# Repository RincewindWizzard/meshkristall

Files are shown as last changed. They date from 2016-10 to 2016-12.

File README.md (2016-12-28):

# meshkristall
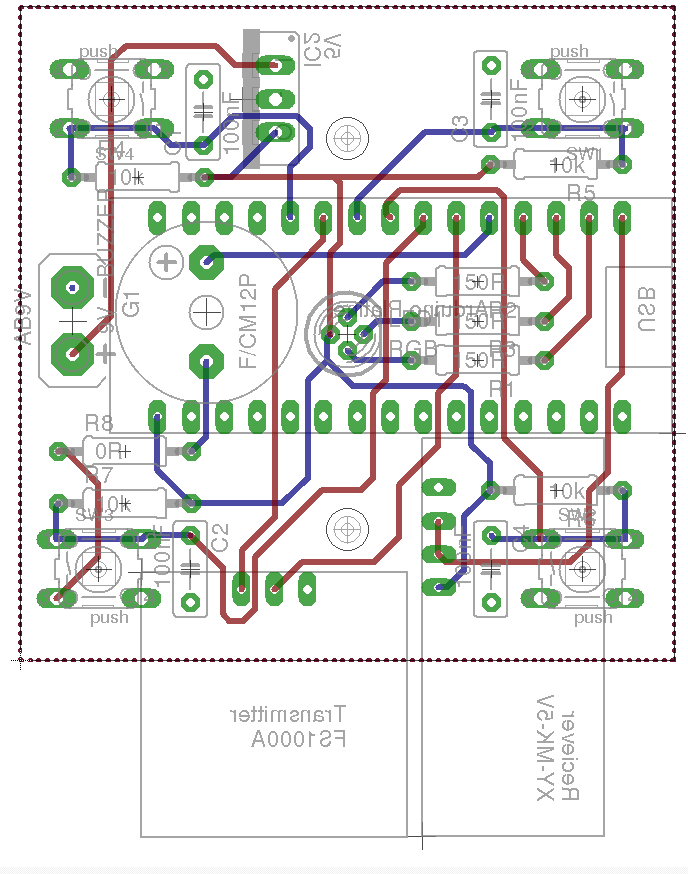
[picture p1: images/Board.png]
Board Layout

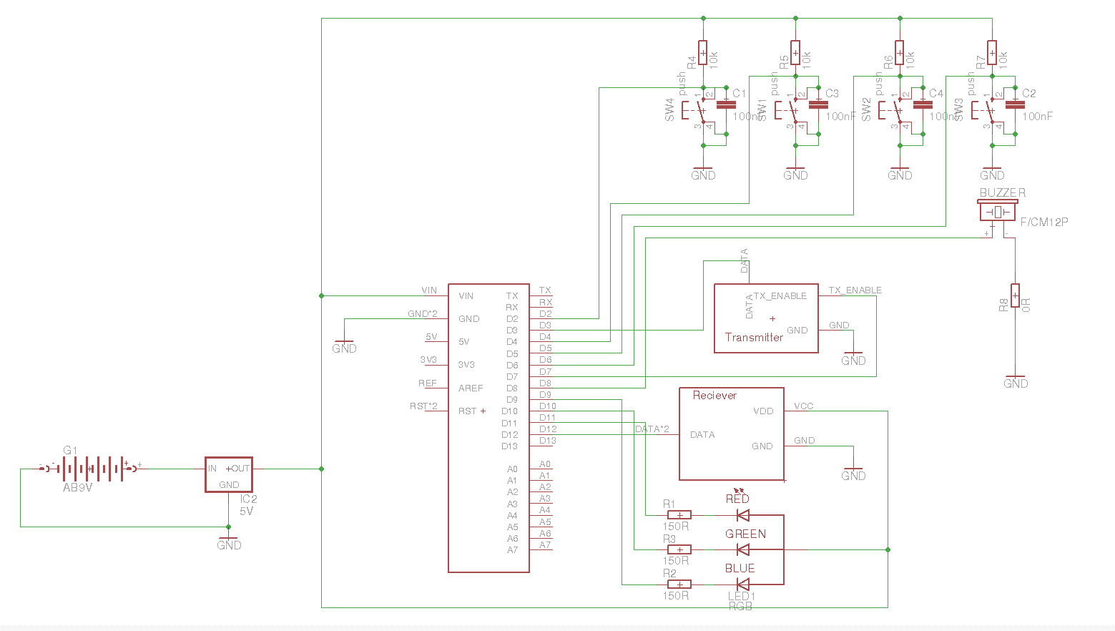
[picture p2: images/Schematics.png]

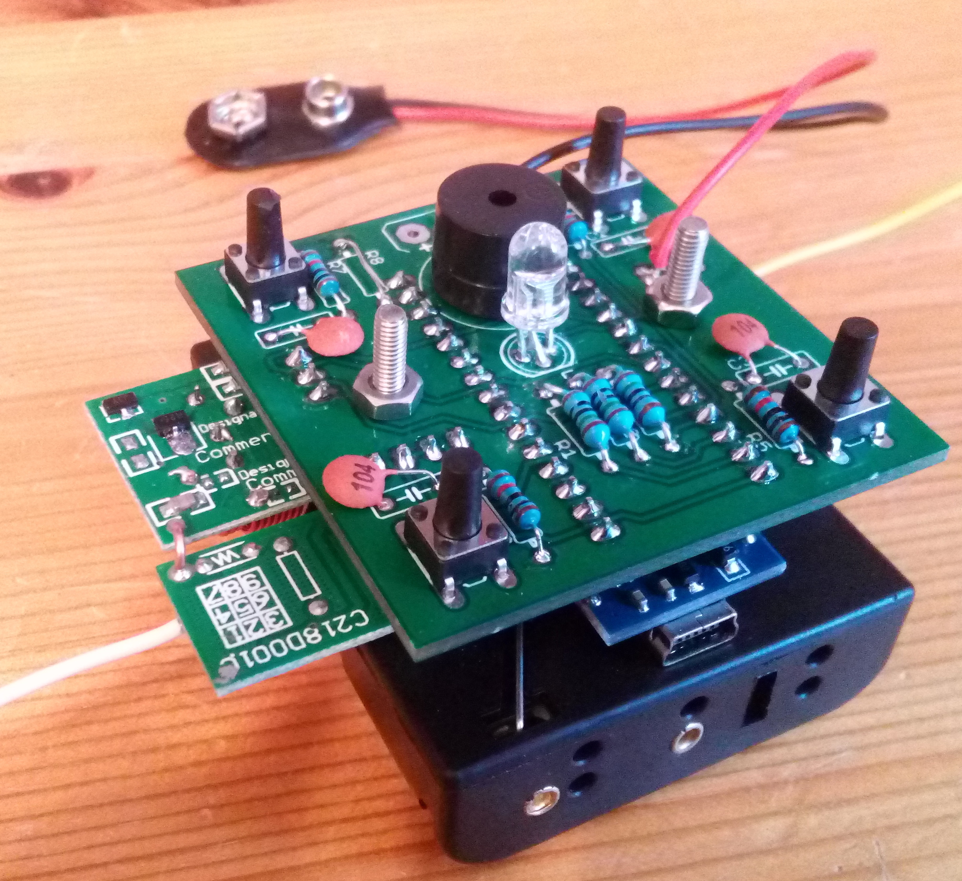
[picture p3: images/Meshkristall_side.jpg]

This project aims to provide a simple board with four buttons and a RGB LED, 
which is capable to communicate over 433 Mhz for interactive radio frequency light installations.

I am planning a case like [this](https://www.youtube.com/watch?v=kgPghSJhkzU) for the board.
The current sketch sends button events over 433 Mhz radio to all other boards. 
Three buttons are connected to the red, green and blue LEDs and the fourth is connected to the remote beepers.
If you press the color buttons, the LED is lit and the current state of buttons is send to the other boards, which show the same color. 
The beeper is only triggered in the remote boards.

Currently the range is only ca. 10 meters, which is nice but not what I need.
As I want to use them as "color telegraphs", they should have a range of 1 kilometer or more.
I will try 2.4 Ghz next. Maybe that works better.

You will find all schematics in this repository.

# Parts list
- [FS1000A](http://www.ebay.de/itm/5X-433-Mhz-RF-Sender-Empfanger-Receiver-Modul-Wireless-Transmitter-MX-05V-DC5V/252441619018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) (433Mhz reciever)
- [XY-MK-5V](http://www.ebay.de/itm/5X-433-Mhz-RF-Sender-Empfanger-Receiver-Modul-Wireless-Transmitter-MX-05V-DC5V/252441619018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)
- [Arduino nano](http://www.ebay.de/itm/MINI-USB-Nano-V3-0-ATmega328P-CH340G-5V-16M-Compatible-Arduino-Nano-V3-0-CY-/191760234382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)

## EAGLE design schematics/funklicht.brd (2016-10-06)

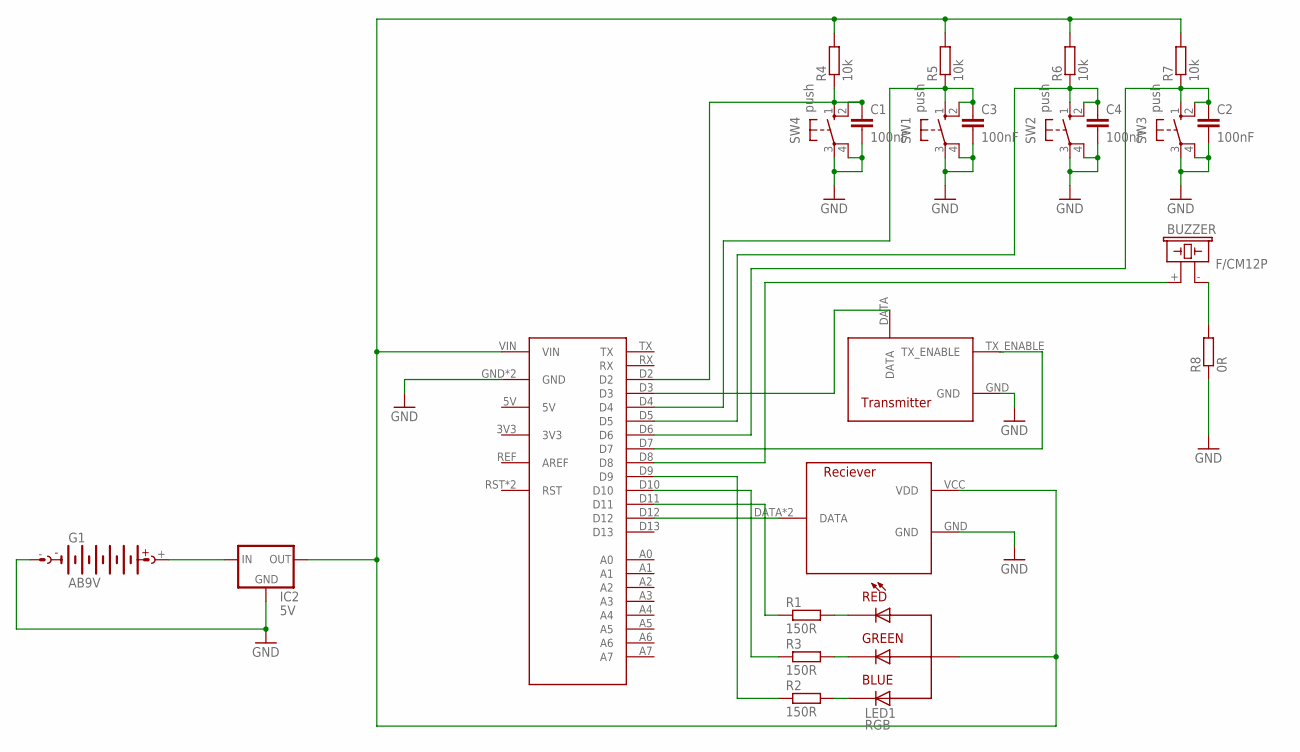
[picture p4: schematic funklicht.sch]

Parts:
BUZZER: F/CM12P
C1, C2, C3, C4: 100nF; C050-025X075
G1: AB9V
IC2: 5V; 78XXS
LED1: RGB; LED5MM
R1, R2, R3: 150R; 0207/10
R4, R5, R6, R7: 10k; 0207/10
R8: 0R; 0207/10
SW1, SW2, SW3, SW4: push; B3F-10XX
U$1: ARDUINO_PLATINE
U$2: RECIEVER
U$3: TRANSMITTER

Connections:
BLUE: LED1.BLUE, R2.2
GND: C1.2, C2.2, C3.2, C4.2, G1.-, IC2.GND, R8.1, SW1.3, SW1.4 (P1), SW2.3, SW2.4 (P1), SW3.3, SW3.4 (P1), SW4.3, SW4.4 (P1), U$1.GND, U$1.GND1 (GND), U$2.GND, U$3.GND
GREEN: LED1.GREEN, R3.2
unnamed: C1.1, R4.1, SW4.1 (S), SW4.2 (S1), U$1.D2
unnamed: U$1.D3, U$3.DATA
unnamed: U$1.D12, U$2.DATA, U$2.DATA1 (DATA)
unnamed: R1.1, U$1.D11
unnamed: R3.1, U$1.D10
unnamed: R2.1, U$1.D9
unnamed: C3.1, R5.1, SW1.1 (S), SW1.2 (S1), U$1.D4
unnamed: C4.1, R6.1, SW2.1 (S), SW2.2 (S1), U$1.D5
unnamed: C2.1, R7.1, SW3.1 (S), SW3.2 (S1), U$1.D6
unnamed: BUZZER.+ (1), U$1.D8
unnamed: BUZZER.- (2), R8.2
unnamed: G1.+, IC2.IN
RED: LED1.RED, R1.2
TX_ENABLE: U$1.D7, U$3.TX_ENABLE
VDD: IC2.OUT, LED1.VCC, R4.2, R5.2, R6.2, R7.2, U$1.VIN, U$2.VCC (VDD)

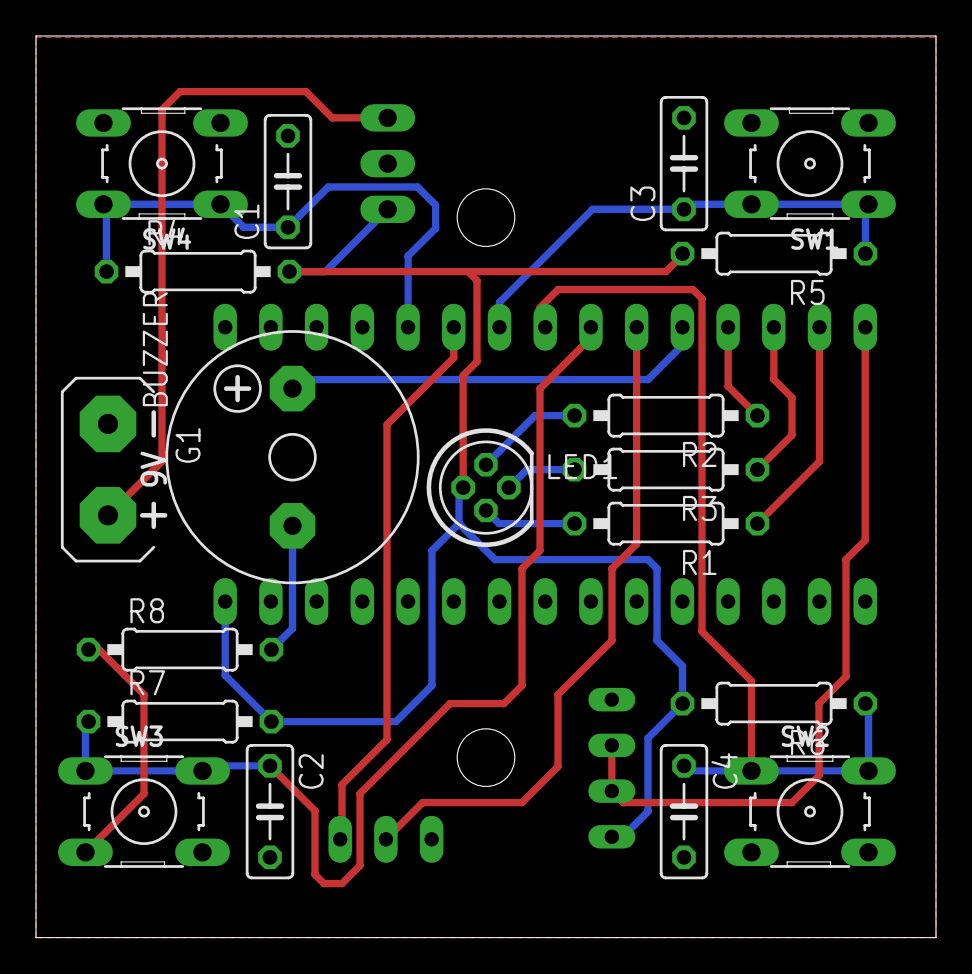
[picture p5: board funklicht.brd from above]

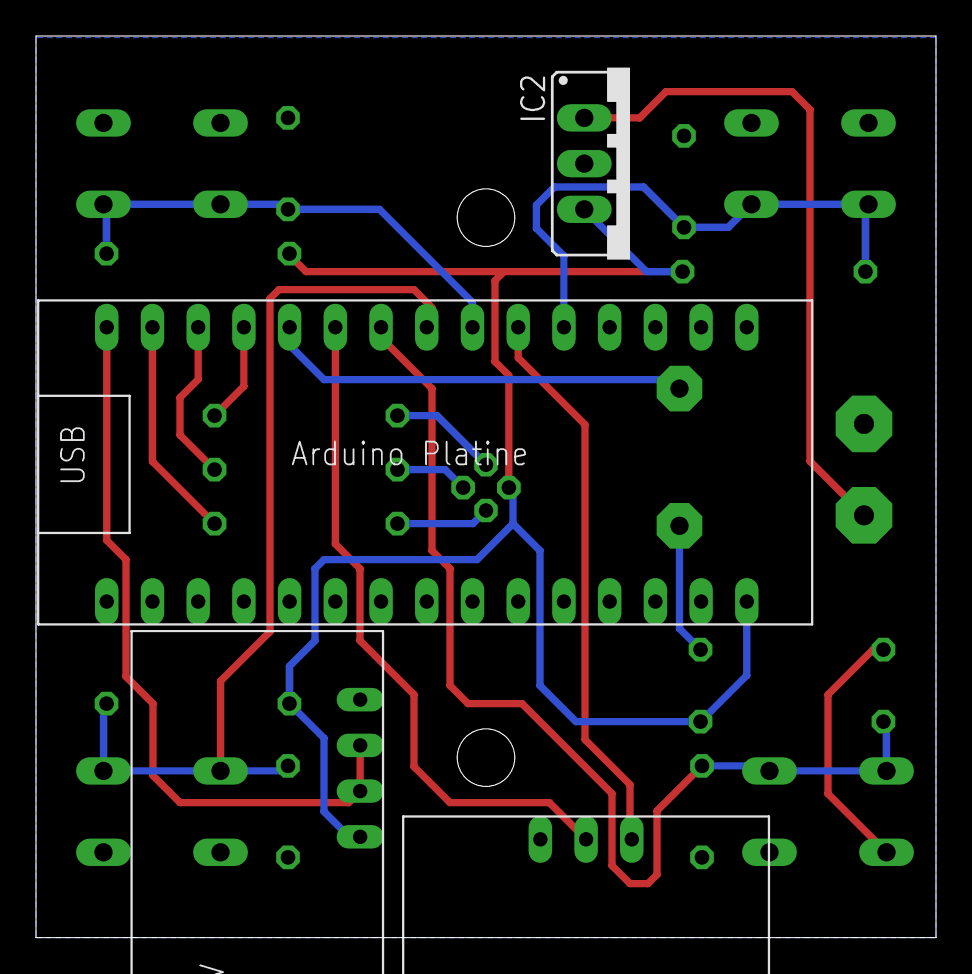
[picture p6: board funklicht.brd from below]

Board: 2 copper layers, 50.0 x 50.1 mm, 23 parts (4 on the bottom side), 18 nets.

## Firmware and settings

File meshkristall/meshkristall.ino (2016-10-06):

#include <VirtualWire.h>

#define DEBUG_LED 13
#define RED_PIN 9
#define GREEN_PIN 10
#define BLUE_PIN 11

#define TX_PIN 3
#define RX_PIN 12
#define TX_EN_PIN 7

#define BTN_0 6 // PCINT22
#define BTN_1 5 // PCINT21
#define BTN_2 4 // PCINT20
#define BTN_3 2 // PCINT18
#define SPEAKER 8


//-----------------------------
#define TX_PIN 3
#define RX_PIN 12
#define TX_EN_PIN 7
//-----------------------------

void setup() {
    // LED
    pinMode(DEBUG_LED, OUTPUT);
    pinMode(RED_PIN, OUTPUT);
    pinMode(GREEN_PIN, OUTPUT);
    pinMode(BLUE_PIN, OUTPUT);
    pinMode(SPEAKER, OUTPUT);
    
    set_rgb(0, 0, 0);
    digitalWrite(DEBUG_LED, LOW);

    // Buttons
    pinMode(BTN_0, INPUT);
    pinMode(BTN_1, INPUT);
    pinMode(BTN_2, INPUT);
    pinMode(BTN_3, INPUT);


    // Enable Pin Change Interrupts for Buttons
    cli();
    PCMSK2 |= _BV(PCINT22) | _BV(PCINT21) | _BV(PCINT20) | _BV(PCINT18);
    PCICR  |= _BV(PCIE2);

    // Initialise the IO and ISR
    vw_set_tx_pin(TX_PIN);
    vw_set_rx_pin(RX_PIN);
    vw_set_ptt_pin(TX_EN_PIN);
    vw_set_ptt_inverted(false); // Required for DR3100
    vw_setup(300);   // Bits per sec

    vw_rx_start();       // Start the receiver PLL running
    sei();
}

bool data_available = false;
uint8_t data = 0;
void loop() {
  
  if(data_available) {
    vw_send(&data, 1);
    delay(10);
    vw_send(&data, 1);
    data_available = false;
  }
  else {
    recieve();
  }
}

void recieve() {
    uint8_t buf[VW_MAX_MESSAGE_LEN];
    uint8_t buflen = VW_MAX_MESSAGE_LEN;
    if (vw_get_message(buf, &buflen)) // Non-blocking
    {
      set_rgb(
        (buf[0]) & 1,
        (buf[0] >> 1) & 1,
        (buf[0] >> 2) & 1
      );
      // trigger alarm
      digitalWrite(SPEAKER, (buf[0] >> 3) & 1);
    }      
}

void set_rgb(uint8_t red, uint8_t green, uint8_t blue) {
  digitalWrite(RED_PIN, !red);
  digitalWrite(GREEN_PIN, !green);
  digitalWrite(BLUE_PIN, !blue);  
}



ISR (PCINT2_vect)
{
  uint8_t red = !digitalRead(BTN_0);
  uint8_t green = !digitalRead(BTN_1);
  uint8_t blue = !digitalRead(BTN_2);
  uint8_t alarm = !digitalRead(BTN_3);
  set_rgb(red, green, blue);
  
  data = (alarm << 3) | (red << 2) | (green << 1) | blue;
  data_available = true;
}
